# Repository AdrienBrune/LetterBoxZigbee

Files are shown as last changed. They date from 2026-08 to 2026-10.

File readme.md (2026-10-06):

<div align="center">

# 📬 Smart Zigbee Mailbox Sensor

<p align="center">
  
</p>

*A discrete, reliable IoT monitoring system for your mailbox powered by an ESP32-C6, wired magnetic reed sensors, and native Zigbee2MQTT integration.*

---









</div>

## 💡 Introduction

Never miss a delivery again! The **Smart Zigbee Mailbox Sensor** is designed to monitor both the main door and the letter flap of your mailbox in real-time. 

Because traditional metal mailboxes act as a Faraday cage that heavily blocks wireless signals, this project features a smart architectural workaround: the core electronics (powered by an **ESP32-H2** with native Zigbee support) are housed in a custom 3D-printed enclosure mounted **externally** outside the metal box. Only the discreet wired reed sensors are routed inside to monitor the openings, ensuring optimal wireless range and zero packet loss while integrating seamlessly into **Home Assistant via Zigbee2MQTT (Z2M)**.

---

## ✨ Key Features

* **Dual-State Detection:** Independently monitors both the main mailbox door and the letter slot flap via dedicated wired magnetic reed switches.
* **Faraday Cage Bypass:** Custom 3D-printed exterior housing places the ESP32-H2 outside the metal structure for maximum Zigbee range and reliability.
* **Native Zigbee2MQTT (Z2M) Support:** Fully compatible with Z2M and Home Assistant out of the box using custom external converter definitions.
* **Low Power & Battery:** ESP32 enters deep sleep to ensure battery life span allowing it to last more than six month.
* **Clean Weatherproof Design:** Discreet external casing designed to blend in cleanly while protecting the microcontroller.

---

## 🛠️ Technical Stack & Hardware

* **Microcontroller:** ESP32-C6 devkit with battery handler module embedded
* **Firmware Language:** C++
* **Communication Protocol:** Zigbee (Zigbee2MQTT compatible)
* **Sensors:** 2x Magnetic Reed Switches (Door + Flap)
* **Smart Home Platform:** Home Assistant via Zigbee2MQTT

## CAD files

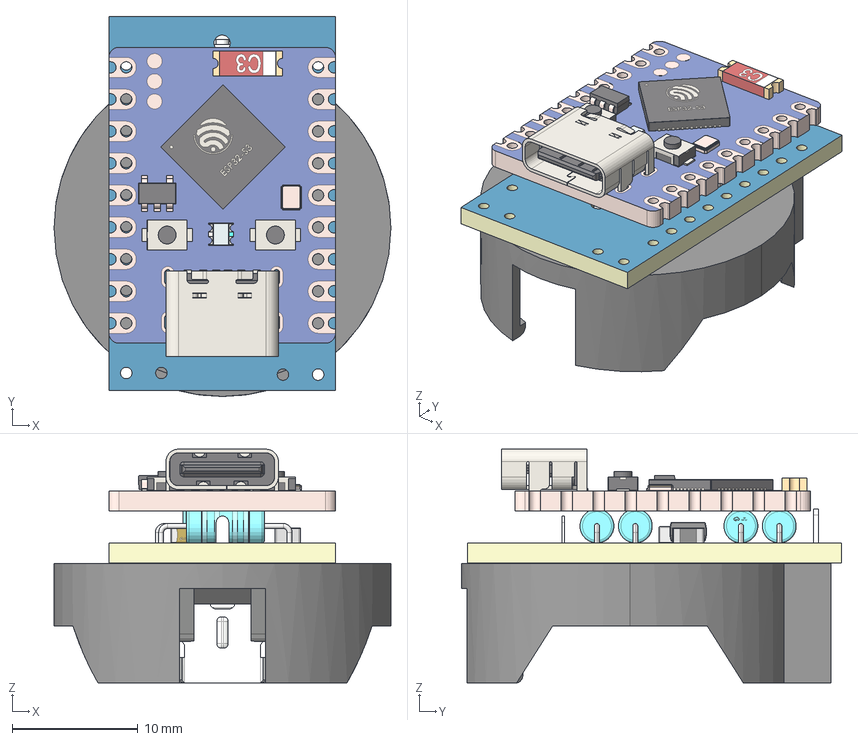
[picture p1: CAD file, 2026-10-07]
3D/boards.step
26.8 x 30.2 x 18.6 mm
Board~D3Ne
TopCopper~D3Ne
BottomCopper~D3Ne
TopFpcStiffener~D3Ne
BottomFpcStiffener~D3Ne
1053~1053.stp~D3Ne
IND-SMD_L2.5-W2.0_MHCHL2520~IND-SMD_L2.5-W2.0_MHCHL2520~D3Ne
ESP32-H2-mini~ESP32-H2-mini.step~D3Ne
C0805~C0805_L2.0-W1.3-H1.3~D3Ne x 2
RES-TH_BD2.7-L6.2-P10.20-D0.4~RES-TH_BD2.7-L6.2-P10.20-D0.4~D3Ne x 4
SOT-23-6_L2.9-W1.6-P0.95-LS2.8-BR~SOT-23-6_ L2.9-W1.6-H1.5-LS2.8-P0.95~D3Ne

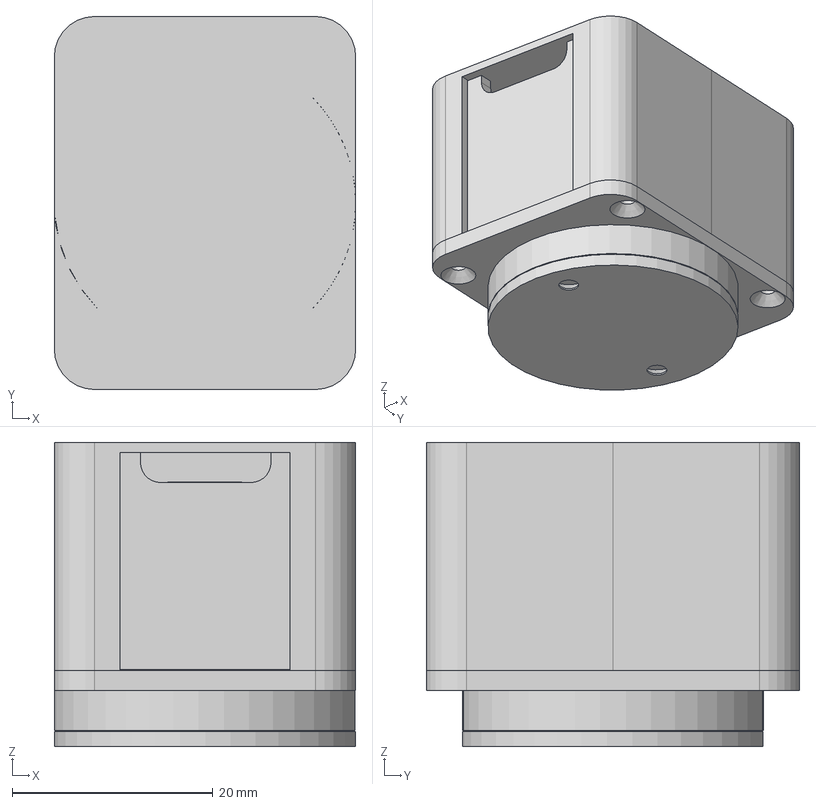
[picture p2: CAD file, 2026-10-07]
3D/letter_box.step
30.0 x 37.1 x 30.3 mm
1053~1053.stp~D3Ne
Board~D3Ne
ESP32-H2-mini~ESP32-H2-mini.step~D3Ne
slider
capot
support

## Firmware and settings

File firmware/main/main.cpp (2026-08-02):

#include "freertos/FreeRTOS.h"
#include "freertos/task.h"
#include "esp_zigbee_core.h"
#include "string.h"
#include "nvs_flash.h"
#include "esp_systick_etm.h"
#include "debug.hpp"
#include "zigbee.hpp"
#include "reed_sensor.hpp"
#include "memory/pers_mem.hpp"

#define LED_PIN 15

#define TIMEOUT_INACTIVITY_MS (uint64_t)20000

void ledPulse()
{
    gpio_set_level((gpio_num_t)LED_PIN, 1);
    vTaskDelay(pdMS_TO_TICKS(50));
    gpio_set_level((gpio_num_t)LED_PIN, 0);
}

void led5Pulse()
{
    for (int i = 0; i < 5; i++)
    {
        ledPulse();
        vTaskDelay(pdMS_TO_TICKS(50));
    }
}

void led20Pulse()
{
    for (int i = 0; i < 4; i++)
    {
        led5Pulse();
    }
}

void _task_zigbee(void *pvParameters)
{
    if(initZigbee() != ESP_OK)
    {
        DebugLogger::getInstance().print(DEBUG_TASK, DEBUG_ERROR, "ZIGBEE init failure");
        return;
    }

    if(initDevice() != ESP_OK)
    {
        DebugLogger::getInstance().print(DEBUG_TASK, DEBUG_ERROR, "ZIGBEE device registration failure");
        return;
    }

    esp_zb_set_rx_on_when_idle(false);

    if(esp_zb_start(false) != ESP_OK)
    {
        DebugLogger::getInstance().print(DEBUG_TASK, DEBUG_ERROR, "ZIGBEE hasn't started");
        return;
    }

    DebugLogger::getInstance().print(DEBUG_TASK, DEBUG_INFO, "ZIGBEE main loop started");
    esp_zb_stack_main_loop();
}


void _task_report(void *pvParameters)
{
    TickType_t startTick = xTaskGetTickCount();

    gpio_set_level((gpio_num_t)LED_PIN, 1);

    esp_sleep_wakeup_cause_t wakeup = esp_sleep_get_wakeup_cause();
    switch (wakeup)
    {
        case ESP_SLEEP_WAKEUP_EXT1:
            DebugLogger::getInstance().print(DEBUG_TASK, DEBUG_INFO, "ESP32 woke up by gpio");
            break;
        case ESP_SLEEP_WAKEUP_TIMER:
            DebugLogger::getInstance().print(DEBUG_TASK, DEBUG_INFO, "ESP32 woke up by timer");
            break;
        default:
            break;
    }

    setupWakeup();

    ReedSensor door(PIN_DOOR), flap(PIN_FLAP);

    vTaskDelay(pdMS_TO_TICKS(500)); // delay before reading sensors
    door.Update();
    flap.Update();

    while (connected.load() != true)
    {
        if ((xTaskGetTickCount() - startTick) >= pdMS_TO_TICKS(TIMEOUT_INACTIVITY_MS))
        {
            led20Pulse();
            enterDeepSleep(); // zigbee connection failure ...
        }

        vTaskDelay(pdMS_TO_TICKS(100)); // wait for zigbee connexion
    }

    gpio_set_level((gpio_num_t)LED_PIN, 0);

    if (wakeup == ESP_SLEEP_WAKEUP_TIMER)
    {
        Battery battery;
        uint16_t level = 0;

        battery.Setup();
        if (battery.GetBatteryPercent(level))
        {
            Memory::GetMemory().Set<uint32_t>(DATA_BATTERY, (uint32_t)level);
            updateBatteryStatus(ZB_EP_BATTERY, level);
            
            ledPulse();
        }

        vTaskDelay(pdMS_TO_TICKS(2000)); // let time for zigbee to send attribute
    }
    else // ESP_SLEEP_WAKEUP_EXT1
    {
        startTick = xTaskGetTickCount();

        while (1)
        {
            door.Update(); // first time skipped because HasChanged() not called yet
            flap.Update(); // first time skipped because HasChanged() not called yet
            if (door.HasChanged() || flap.HasChanged())
            {
                startTick = xTaskGetTickCount(); // reset timer
                
                updateReedStatus(ZB_EP_DOOR, door.IsOpened());
                updateReedStatus(ZB_EP_FLAP, flap.IsOpened());

                uint16_t batteryLevel = (uint16_t)Memory::GetMemory().Get<uint32_t>(DATA_BATTERY);
                updateBatteryStatus(ZB_EP_BATTERY, batteryLevel);

                ledPulse();
            }

            if (door.IsClosed() && flap.IsClosed())
            {
                if ((xTaskGetTickCount() - startTick) >= pdMS_TO_TICKS(TIMEOUT_INACTIVITY_MS))
                {
                    break; // ready to enter deep sleep
                }
            }

            vTaskDelay(pdMS_TO_TICKS(1000));
        }
    }

    led5Pulse();
    enterDeepSleep();
}


extern "C" void app_main(void)
{
    esp_err_t err = nvs_flash_init();
    if (err == ESP_ERR_NVS_NO_FREE_PAGES || err == ESP_ERR_NVS_NEW_VERSION_FOUND)
    {
        DebugLogger::getInstance().print(DEBUG_GENERIC, DEBUG_ERROR, "NVS flash init");
        ESP_ERROR_CHECK(nvs_flash_erase());
        err = nvs_flash_init();
    }
    if (err != ESP_OK)
    {
        DebugLogger::getInstance().print(DEBUG_GENERIC, DEBUG_ERROR, "NVS init failure, program stopped");
        return;
    }

    esp_zb_platform_config_t config = {
        .radio_config = { .radio_mode = ZB_RADIO_MODE_NATIVE },
        .host_config = { .host_connection_mode = ZB_HOST_CONNECTION_MODE_NONE },
    };
    if(esp_zb_platform_config(&config) != ESP_OK)
    {
        DebugLogger::getInstance().print(DEBUG_GENERIC, DEBUG_ERROR, "ZIGBEE init failure, program stopped");
        return;
    }

    Memory::GetMemory().Load();

    gpio_set_direction((gpio_num_t)LED_PIN, GPIO_MODE_OUTPUT);

    DebugLogger::getInstance().print(DEBUG_GENERIC, DEBUG_INFO, "init completed");

    xTaskCreate(_task_zigbee, "zigbee", 8124, NULL, 3, NULL);
    xTaskCreate(_task_report, "report", 4096, NULL, 2, NULL);
}

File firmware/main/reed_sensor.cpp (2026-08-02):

#include "reed_sensor.hpp"
#include "debug.hpp"
#include "esp_sleep.h"
#include "zigbee.hpp"
#include <map>
#include <algorithm>
#include <cmath>
#include <vector>
#include <numeric>

#define US_TO_SEC (uint64_t)1000000

void setupWakeup()
{
    gpio_config_t io_conf = {
        .pin_bit_mask = (1ULL << PIN_DOOR) | (1ULL << PIN_FLAP),
        .mode = GPIO_MODE_INPUT,
        .pull_up_en = GPIO_PULLUP_DISABLE, // external pull-up
        .pull_down_en = GPIO_PULLDOWN_DISABLE,
        .intr_type = GPIO_INTR_DISABLE
    };
    gpio_config(&io_conf);

    uint64_t mask = (1ULL << PIN_DOOR) | (1ULL << PIN_FLAP);
    esp_sleep_enable_ext1_wakeup_io(mask, ESP_EXT1_WAKEUP_ANY_HIGH);

    esp_sleep_enable_timer_wakeup(REPORTING_MAX_PERIOD_SEC * US_TO_SEC);
    DebugLogger::getInstance().print(DEBUG_SLEEP, DEBUG_INFO, "Automatic wakeup setup to %d seconds", REPORTING_MAX_PERIOD_SEC);
}

void enterDeepSleep()
{
    while(1)
    {
        if (gpio_get_level(PIN_DOOR) == 1 || gpio_get_level(PIN_FLAP) == 1)
        {
            DebugLogger::getInstance().print(DEBUG_SLEEP, DEBUG_WARNING, "gpio not correctly setup, ESP32 can't enter deep sleep");
            vTaskDelay(pdMS_TO_TICKS(1000));
        }
        else
        {
            DebugLogger::getInstance().print(DEBUG_SLEEP, DEBUG_INFO, "ESP32 will enter deep sleep ...");
            esp_deep_sleep_start();
        }
    }
}


void ReedSensor::Update()
{
    if (m_changed)
    {
        DebugLogger::getInstance().print(DEBUG_REED, DEBUG_WARNING, "reed sensor status reading requested but last value has not been used");
        return;
    }

    int status = gpio_get_level(m_pin);
    if (status != m_status)
    {
        m_changed = true;
        m_status = status;
    }
}


void Battery::Setup()
{
    adc_oneshot_unit_init_cfg_t config_unit = {
        .unit_id = ADC_UNIT_1,
        .clk_src = ADC_DIGI_CLK_SRC_DEFAULT,
        .ulp_mode = ADC_ULP_MODE_DISABLE
    };
    if (adc_oneshot_new_unit(&config_unit, &m_handle) != ESP_OK)
    {
        DebugLogger::getInstance().print(DEBUG_ADC, DEBUG_ERROR, "Setup ADC unit failure");
        return;
    }

    adc_oneshot_chan_cfg_t config_ch = {
        .atten = ADC_ATTEN_DB_6,
        .bitwidth = ADC_BITWIDTH_12,
    };
    if (adc_oneshot_config_channel(m_handle, ADC_CHANNEL_0, &config_ch) != ESP_OK)
    {
        DebugLogger::getInstance().print(DEBUG_ADC, DEBUG_ERROR, "Setup ADC channel failure");
        return;
    }
}

bool Battery::GetBatteryPercent(uint16_t& level)
{
    uint16_t adu = 0;
    if (!_GetAverageMeasurement(adu))
    {
        return false;
    }

    // experimental result
    static const std::map<uint16_t, float> batteryLevelMapAdc = {
        {4096, 100.0f},
        {3850, 86.0f},
        {3277, 5.9f},
        {2768, 0.0f}
    };

    // linear interpolation
    float percent = 0.0f;
    if (adu <= batteryLevelMapAdc.begin()->first)
    {
        percent = 0.0f;
    } 
    else if (adu >= batteryLevelMapAdc.rbegin()->first)
    {
        percent = 100.0f;
    } 
    else
    {
        auto itUpper = batteryLevelMapAdc.lower_bound(adu);
        auto itLower = std::prev(itUpper);

        uint16_t adu1 = itLower->first;
        float p1 = itLower->second;
        uint16_t adu2 = itUpper->first;
        float p2 = itUpper->second;

        percent = p1 + ((adu - adu1) * (p2 - p1) / (adu2 - adu1));
    }
    level = static_cast<uint16_t>(std::clamp(std::ceil(percent), 0.0f, 100.0f));

    DebugLogger::getInstance().print(DEBUG_ADC, DEBUG_INFO, "Battery: %2.0f (adu: %d)", level, adu);

    return true;
}

bool Battery::_GetAverageMeasurement(uint16_t& averageAdu)
{
    const int numSamples = 12;
    const int numSamplesRemoved = 6;
    std::vector<int> samples;

    samples.reserve(numSamples);
    for (int i = 0; i < numSamples; i++)
    {
        int adu = 0;
        if (adc_oneshot_read(m_handle, ADC_CHANNEL_0, &adu) != ESP_OK)
        {
            DebugLogger::getInstance().print(DEBUG_ADC, DEBUG_ERROR, "Measurement ADC failure");
            return false;
        }
        samples.push_back(adu);

        vTaskDelay(pdMS_TO_TICKS(500));
    }

    int sum = std::accumulate(samples.begin(), samples.end(), 0.0f);
    int average = sum / samples.size();
    std::sort(samples.begin(), samples.end(), 
        [average](int a, int b)
        {
            return std::abs(a - average) < std::abs(b - average);
        }
    );

    // remove 5 extremum values
    int refinedSum = std::accumulate(samples.begin(), samples.begin() + numSamplesRemoved, 0);
    averageAdu = static_cast<uint16_t>(refinedSum / numSamplesRemoved);

    return true;
}

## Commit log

2026-08-02 fix battery discharge algo
    [battery-level.ods]
2026-10-07 move files
    [battery-level.ods, boards.step, letter_box.step]
